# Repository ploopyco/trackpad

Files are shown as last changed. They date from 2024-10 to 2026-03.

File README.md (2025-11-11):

# The Ploopy Trackpad

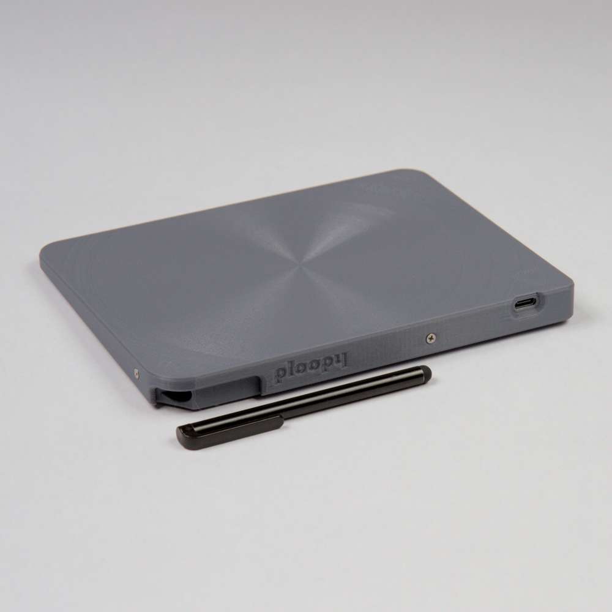
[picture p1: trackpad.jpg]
The Ploopy Trackpad


By some stroke of luck, you've made your way here. The Ploopy Trackpad. Your life will never be the same.

This repository contains all of the design and production files necessary to make a Ploopy Trackpad. We've also included some kick-ass documentation on how to get it made, assemble it, and program it [which you can find here](https://ploopyco.github.io/trackpad/).

What are you waiting for? Your new life awaits.

## QMK?!

Kits bought from the [Ploopy store](https://ploopy.co/product-category/trackpad/) come with QMK preloaded. [Check out the documentation](https://ploopyco.github.io/trackpad/) for instructions on how to load new firmware onto your device. (It's super easy!)

The firmware for the Trackpad hasn't been merged into QMK at the time of this commit, so for now, [firmware can be found here](https://github.com/ploopyco/qmk_firmware/tree/multitouch_experiment).

The firmware hex file that ships with all Trackpads is included in this repository as well, as `ploopyco_pavonis_default.uf2`.

A version of the firmware that is used for debugging and development is included here, as `ploopyco_pavonis_debug.uf2`. Don't use this firmware unless you need to use the [Maxtouch Debug App](https://ploopyco.github.io/trackpad/appendices/debugapp/).

## Under what license is this released?

As per QMK's licensing requirements, the firmware for the Ploopy Trackpad is released under GPLv3. Hardware design files, including electronics and mechanical files, are released under OHL CERN v2-S. Check the respective directories for full license text.

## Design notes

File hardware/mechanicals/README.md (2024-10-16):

## Only one file? Where are the parts?

The STEP/STL files contain all of the plastic parts in one file. Doing it this way preserves the assembly information, showing how the parts are supposed to fit together, as well as the expected clearances between parts. It also bundles all of the parts for a given revision together, so there's no accidental mixing of parts from different revisions.

## How do I print this?

You'll need to split the parts in the file up before you can print them. Most slicers can do this; if you have a compatible printer we recommend PrusaSlic3r, since that's the one we use in-house and have checked.

Note that submitting this file to some 3rd party print services will cause confusion, as they are expecting one body instead of many. To do this, you can use PrusaSlic3r to split the parts and then export each separately as an STL.

## How can I use the included .3mf file?

The .3mf file was generated using PrusaSlicer v2.5. The job was generated for Prusa i3 MK2S/MK3S/MK3S+ printers. It assumes the use of PLA that is printable at 200-230C. If you have that PrusaSlicer version, such a printer, and such filament, then you're in a lot of luck! We use a .3mf job that is very similar to this one to print these parts on our printing farm.

If you do not, then using the included .3mf file is likely going to cause you a lot of headaches. If this is the case, the included .3mf file should be considered **as a reference only**. If you use it at all, it is recommended that you look at it to see what kinds of print settings we use (gyroid infill, 0.3mm layer height, part orientation, etc.). However, you should use your own slicing software to generate the .gcode files for your printer.

## Why don't you include a .gcode file?

For your safety. Uploading a .gcode file onto a printer can be extremely hazardous if that .gcode file wasn't specifically generated for that printer. We don't want to come anywhere near that sort of scenario, so we are not going to upload a .gcode file.

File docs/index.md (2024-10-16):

# Home

So, you want to build a Ploopy Trackpad, eh? Or, maybe you want to replace some broken parts. Maybe you want to reprogram it. Or maybe you just want to know how it all works. No matter the motivation, this is the place to learn.

**Bought a kit and itching to get it built?** --> Get started by going to the [assembly instructions](assembly-instructions.md).

**Looking to purchase a kit with everything you need to build your own Ploopy Trackpad?** --> [Check out the Ploopy store](https://ploopy.co/product-category/trackpad).

**Building a Ploopy Trackpad from scratch?** --> Get started by going to [Appendix A: Printed circuit boards](appendices/pcbs.md).

---

*Copyright (C) 2024 Ploopy Corporation. Permission is granted to copy, distribute and/or modify this document under the terms of the GNU Free Documentation License, Version 1.3 or any later version published by the Free Software Foundation; with no Invariant Sections, no Front-Cover Texts, and no Back-Cover Texts. A copy of the license is included in the section entitled "GNU Free Documentation License".*

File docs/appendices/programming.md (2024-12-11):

# Appendix D: QMK Firmware Programming

## Working with QMK

Ploopy devices are fairly easy to program and reprogram, thanks to the excellent work by all of the developers and maintainers of the [QMK firmware suite](https://github.com/qmk/qmk_firmware).

## Pavonis? What's that?

`pavonis` is our internal codename for the Ploopy Trackpad. We don't always know what we're going to call the devices as we're designing them, so we assign codenames to them. This naming convention is also present in some public places, such as the QMK repository. If you see `pavonis` while you're working with QMK, just know that the Trackpad and `pavonis` are the same thing.

## Before you begin

If you have never used QMK before, go through [all of the steps in the QMK guide to set up your environment](https://docs.qmk.fm/#/newbs_getting_started).

QMK was built for keyboards, so you'll see lots of references to code that looks like the following:

`-kb <keyboard>`

Whenever you see that, use the following syntax:

`-kb ploopyco/pavonis`

and you'll be fine.

## Building the Ploopy device firmware

With your terminal window open and pointed at your QMK build environment, compile the firmware with the following command:

`qmk compile -kb ploopyco/pavonis -km default`

Alternatively, you can invoke the Makefile directly with the following:

`make ploopyco/pavonis:default`

For more details on building QMK firmware in general, see the [QMK firmware guide](https://docs.qmk.fm/#/newbs_building_firmware).

## Putting the Ploopy device into bootloader mode

Putting the Ploopy device into bootloader mode is very simple and straightforward.

1. Unplug the device from your computer.
2. Flip it over onto it's back. Unscrew the bootloader cap.
3. You should see two gold-covered holes exposed on the PCB once the cap is removed.
4. Get a paper clip (non-insulated, i.e. no plastic shit covering it) or a pair of tweezers, or some wire. Whatever you've got on hand that's metal.
5. Stick the paper clip or tweezers into the holes. You're trying to form an electrical connection between the two holes.
6. While you've got the two vias connected with your metal bridge, plug the Ploopy device into your computer.
7. The computer should recognise that a mass storage device was just plugged in. Once this is done, you should be able to drag and drop files onto the Ploopy device, as if the board was a USB drive. Feel free to remove the tweezers or paperclip at this point.

And that's it. While plugged in this way, the Ploopy device will accept new firmware.

If you want to upload a new firmware file (a ".uf2" file, like "ploopy_trackpad_v42069" or something), just drag it into the folder, and it'll automatically install on the Ploopy device and restart itself.

Whenever you want to put new firmware onto the Ploopy device, go through these steps again.

**TIP**: If your firmware is in some kind of strange state and uploading new firmware isn't fixing it, try uploading [a flash nuke](https://learn.adafruit.com/getting-started-with-raspberry-pi-pico-circuitpython/circuitpython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) to the Trackpad before flashing the new firmware. It wipes the memory of the Trackpad completely clean, which can help clear a few types of errors.

## And that's it!

Happy customizing!

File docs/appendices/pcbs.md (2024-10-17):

# Appendix A: Printed circuit boards

## Buying boards from us
Getting the Ploopy boards made can be complex, and expensive, especially if you only need one set. [That's why we sell kits with everything you need to build a Ploopy Trackpad](https://ploopy.co/product-category/trackpad/). Here's why that's great for you:

- You get a PCB with all components soldered
- The firmware is already programmed on the microcontroller, so you won't have to program it
- It'll cost a hell of a lot less than if you do a production run of PCBs just for yourself
- You won't have to order components and wait while they come in
- We guarantee that it works

Just something to consider. You're smart. You'll figure it out.

## Making your own boards

Want to make your own Ploopy Trackpad boards? Great! Less work for us. Seriously, though, only choose this option if you know what you're doing. You don't want to embarrass yourself, do you?

### Step 1: Order the PCBs from a PCB production company

Here are the most important configurations you'll need to communicate to the company:

- 6 layers
- FR-4, TG 150-160 (basically, whatever the cheapest option is)
- 1.6mm thickness
- 6/6mil track/spacing distance
- 0.3mm minimum hole size
- ENIG surface finish, but you can go with HASL if you don't care about lead poisoning
- 1oz copper thickness for both outer and inner layers
- Choose whatever colours you want for solder mask and silkscreen; we like white solder mask and black silkscreen

If something is missing from here, it's not really important.

At some point, you'll have to upload design files to the production company. Use the [electronics source files](https://github.com/ploopyco/trackpad/tree/master/hardware/electronics) to generate manufacturing files (you'll have to convert them from their native Altium format if you're using some other platform). That should contain everything you need to get the boards made. If the production company rejects this package, however, you'll need to address the issue yourself.

### Step 2: Order the electronics components

All of the components are described in the schematics of the PCBs. Ordering the components is left as an exercise for the reader.

A complete list of all of the components can be found in the electrical design files.

### Step 3: Get the necessary tools

- PCB
- All of the electronics components
- A hot air rework tool
- Solder paste
- A printout of the schematics

### Step 4: Solder the components to the boards

Once you've got the PCBs and all of the components, print out the schematics. Use the schematics to match the reference designators on the PCBs to the reference designators on the schematics, and then get to soldering.

If you've never soldered surface mount components before, or want a refresher on how to solder, we recommend [this video on using an iron to solder surface mount components](https://www.youtube.com/watch?v=3NN7UGWYmBY), and [this video on using a hot-air soldering station](https://www.youtube.com/watch?v=c_Qt5CtUlqY).

### Step 5: All done!

Congrats, you finished assembling the electronics! Pat yourself on the back.

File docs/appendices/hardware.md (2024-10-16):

# Appendix C: Hardware

# Buying hardware from us

Getting all of the hardware on your own can be tricky because the parts you select may not fit perfectly. [That's why we sell kits with everything you need to build a Ploopy Trackpad](https://ploopy.co/product-category/trackpad/). Here's why that's great for you:

- Everything is guaranteed to fit together perfectly
- Everything is guaranteed to work as intended
- You'll end up saving money - probably quite a bit of money - by not spending on extra parts

Your call. You'll sort it out.

# Getting your own hardware

This guide was a bit light on detail in the other sections, and that's because the hardware has to conform to many specifications. They'll all be listed here.

First, a complete list of all the hardware you'll need:

- 4x Small Screws
- 4x Friction Pads
- 1x Tape

We'll be going over all of them in detail. There will be mentions of *critical specifications*; if you're going to be sourcing your own parts, **you must get parts that conform to the critical specifications**. If you go off-menu, the parts will not fit the way that we intended when we designed the trackball. That might mean that your trackball **doesn't work**.

Let's get cracking.

## Small Screws

Here are the critical specifications:

- \#2
- 3/8" length

## Friction pads

Here are the critical specifications:

- Circular shape
- Up to 3/4" diameter
- Up to 1/8" thickness
- Non-slip

## Tape

We use **3M 467MP** adhesive transfer tape in dimensions of 6" x 4". If you do not use this specific tape, you may find that the tracking is extremely erratic, or may not function at all. If you decide to use other tapes, you will be responsible for retuning the Trackpad.

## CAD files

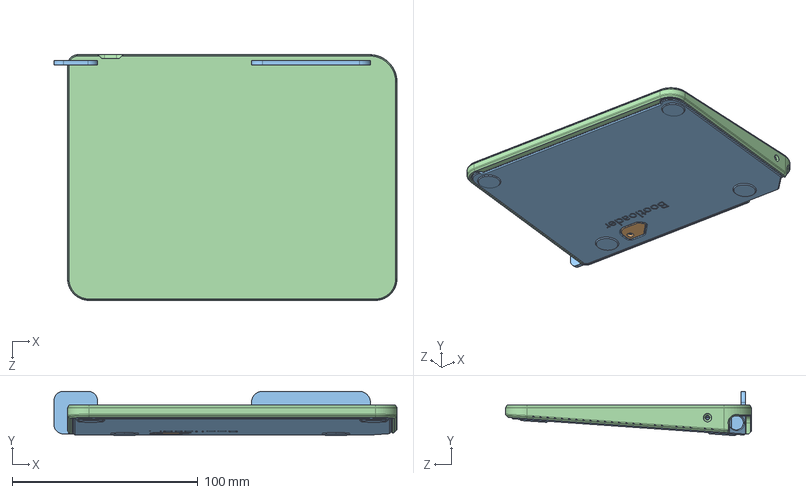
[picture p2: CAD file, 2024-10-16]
hardware/mechanicals/PloopyTrackpad-RevA.STEP
184.5 x 23.9 x 132.2 mm

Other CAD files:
hardware/mechanicals/PloopyTrackpad-RevA.3mf
hardware/mechanicals/PloopyTrackpad-RevA.STL

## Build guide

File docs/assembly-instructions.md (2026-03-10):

# Ploopy Kit Assembly Instructions

## BEFORE YOU DO ANYTHING, READ THIS FIRST.

**Do not flash new firmware until you've verified that the electronics are all working.**

That means, finish building the trackpad, plug it in, use the stock firmware for about five minutes. Verify that the cursor is moving, and all the buttons are working.

Once you've verified that it all works, you're good to go flashing new firmware.

## Main Instructions

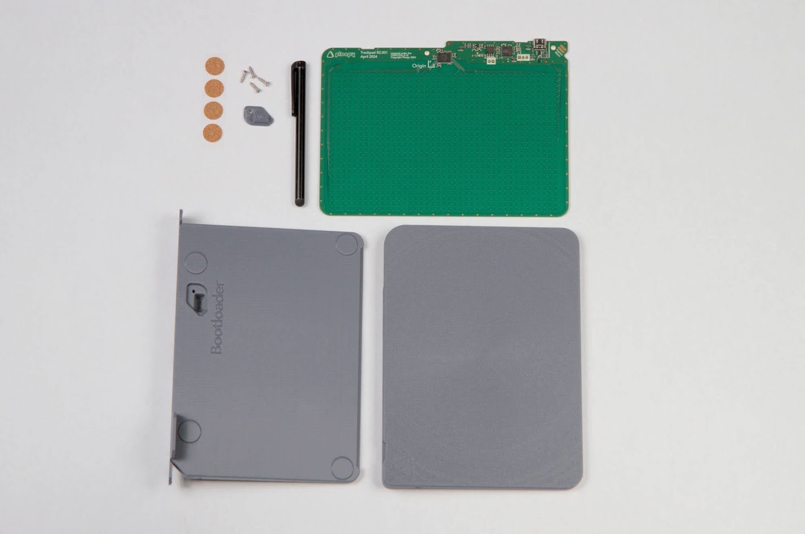
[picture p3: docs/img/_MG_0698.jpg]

In this section, you'll go over how to build a Trackpad from the official Ploopy Trackpad kit.

Here's how these instructions are structured*:

- 💡 Comments with a lightbulb are good information to know.
- ➡️ Comments with an arrow are commands. Execute them when you encounter them.
- ✅ Comments with a checkmark are verification steps. Check what they tell you to check, and if it's all good, move on.
- 📷 Comments with a camera are references to photos. Check the corresponding image for guidance.

Most steps have photos, so if you need some additional visual help, consult the images.

Note that some of these pictures were taken at different times, so they may show a bit of inconsistency in between steps.

*\* Thanks to [schneems](https://github.com/schneems) for his [great suggestions on how to write documentation](https://github.com/ploopyco/headphones/issues/37).*

### Step 1

- ➡️Get a #1 Phillips head screwdriver (or similar; you're looking for a small-ish screwdriver here).
- ➡️Get pair of pliers.
- 💡A pair of tweezers are optional, but they'll make future steps easier.

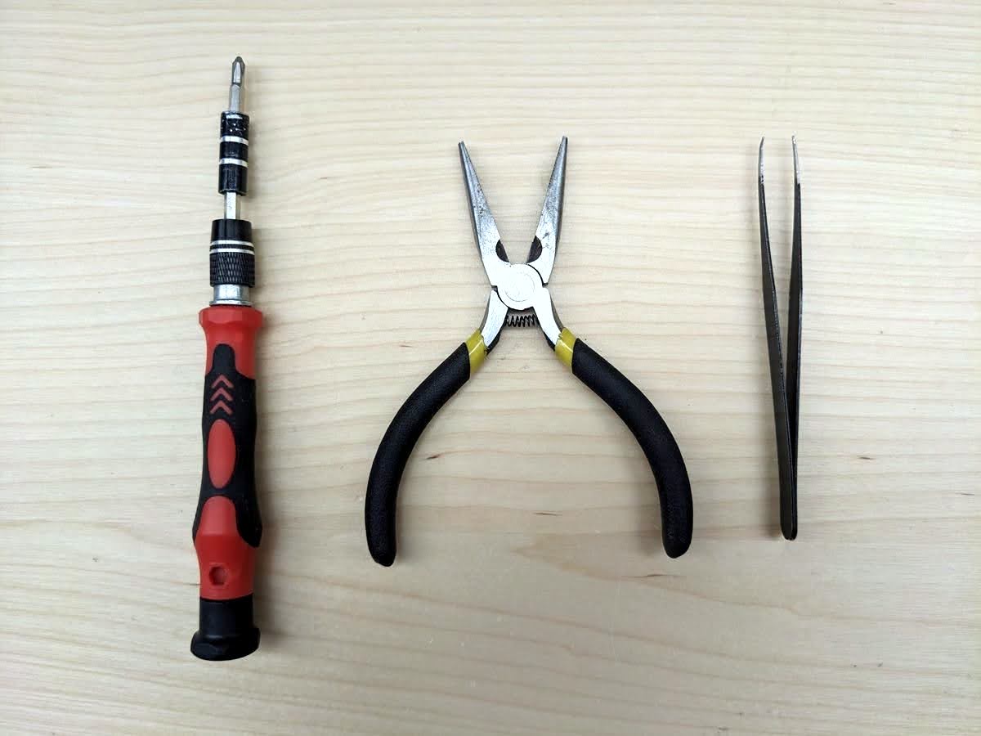
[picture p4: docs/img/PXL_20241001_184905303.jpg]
|  |
|:--:|
| *Figure 1: Necessary tools* |

### Step 2

- 💡 In the photo, a "tab" is being pulled by a pair of pliers.
- 💡 There may be up to two small tabs on the outside of the PCB.
- 💡 A pair of pliers will help to gently break the tabs off.
- ➡️ Break any leftover tabs off the PCB.

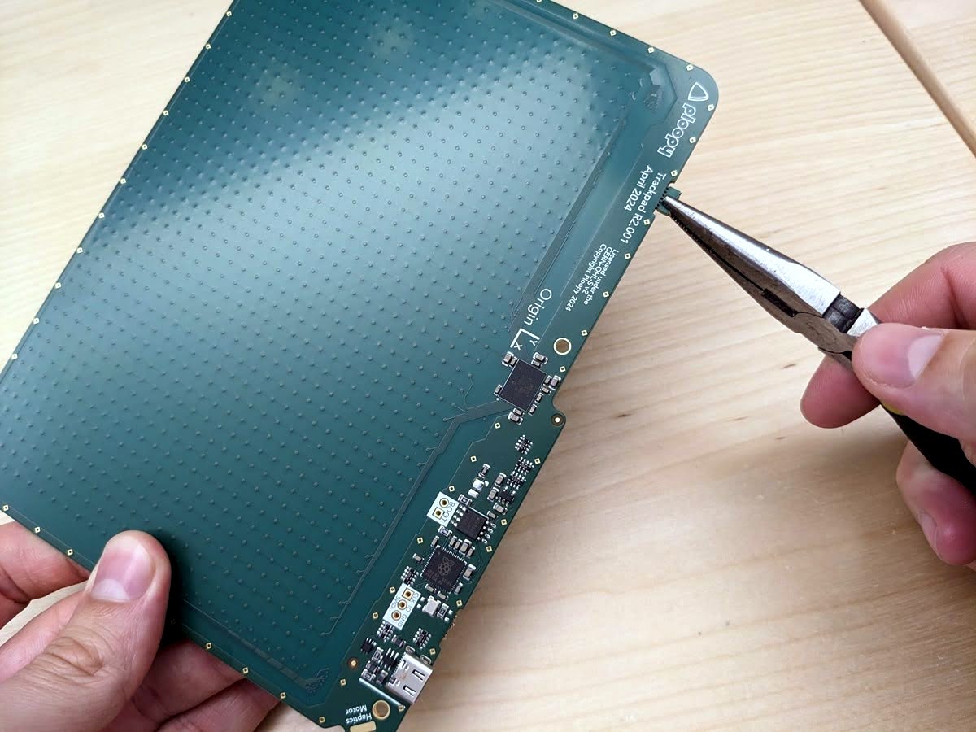
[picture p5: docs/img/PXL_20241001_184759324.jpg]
|  |
|:--:|
| *Figure 2: Breaking off tabs* |

### A Brief Note about Tape

- 💡 Trackpads shipped prior to March 2026 will have a large rectangle of 3M adhesive tape applied to the rear of the PCB. After March 2026, Trackpad PCBs will not have this layer of tape, as it was deemed unnecessary.
- 💡 If your Trackpad has tape on it, you do not have to peel the protective layer of tape off, and you do not have to stick the PCB to the plastic. Proceed through these instructions and ignore the tape.

### Step 3

- ➡️ Get the PCB and Front. 📷 *See Figure 3.1.*
- ➡️ Place the PCB into the Front. 📷 *See Figure 3.2.*
- ✅ Check that the USB port lines up with the hole in the Front, and that the PCB is sitting flat against the Front. 📷 *See Figure 3.3.*

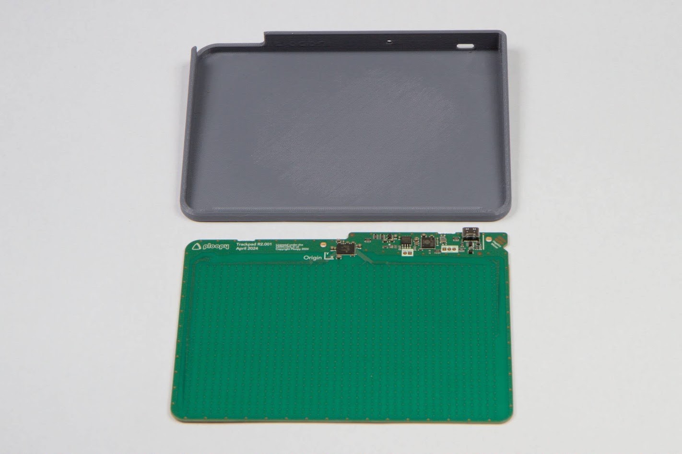
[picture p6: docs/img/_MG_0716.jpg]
|  |
|:--:|
| *Figure 3.1: PCB and Front* |

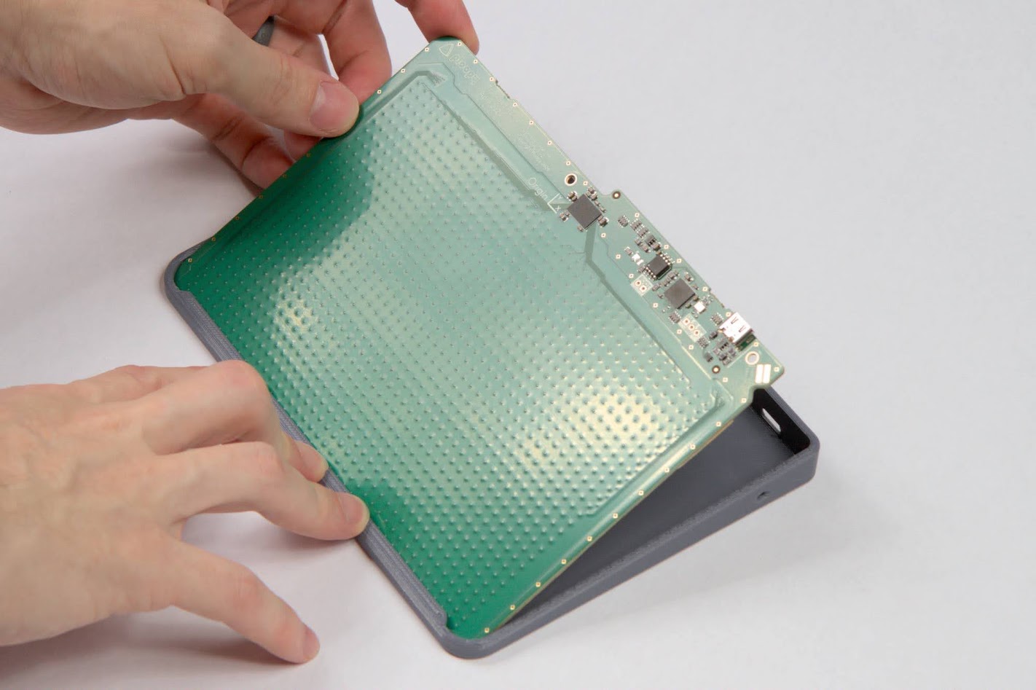
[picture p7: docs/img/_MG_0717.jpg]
|  |
|:--:|
| *Figure 3.2: PCB being placed into Front* |

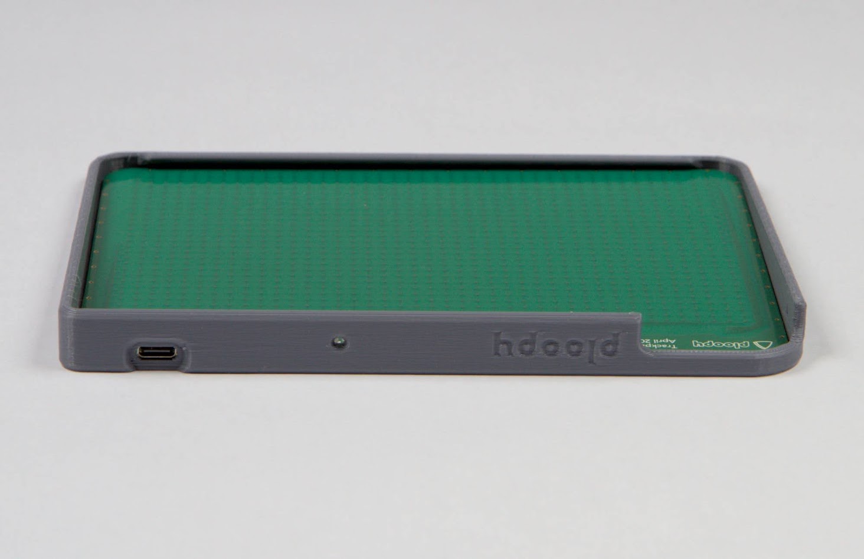
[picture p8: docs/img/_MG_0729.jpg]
|  |
|:--:|
| *Figure 3.3: PCB placed correctly, with PCB sitting flat and USB port lined up with hole* |

### Step 4

- ➡️ Get the Back. 📷 *See Figure 4.1.*
- 💡 Note the lip on the bottom of the Front.
- 💡 It might require a bit of force to press the Back into the assembly.
- ➡️ Place the Back into the assembly. 📷 *See Figure 4.2 and Figure 4.3.*

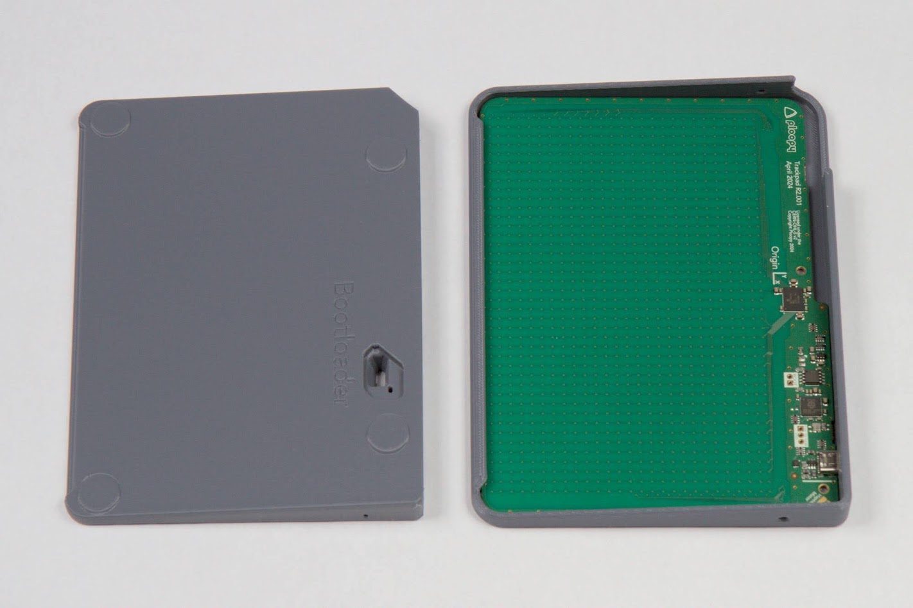
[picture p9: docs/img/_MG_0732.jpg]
|  |
|:--:|
| *Figure 4.1: Back and assembly* |

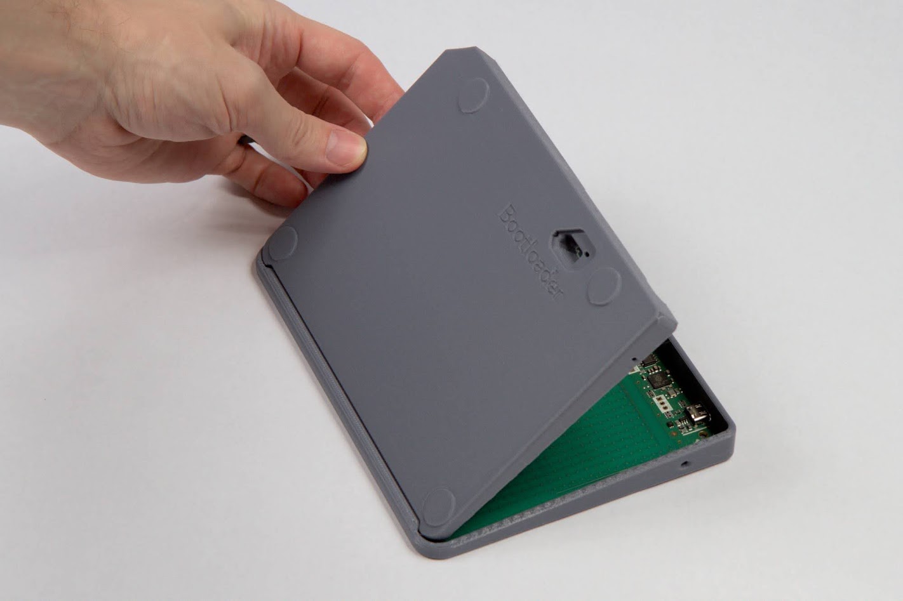
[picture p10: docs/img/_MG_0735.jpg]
|  |
|:--:|
| *Figure 4.2: Back being placed into assembly* |

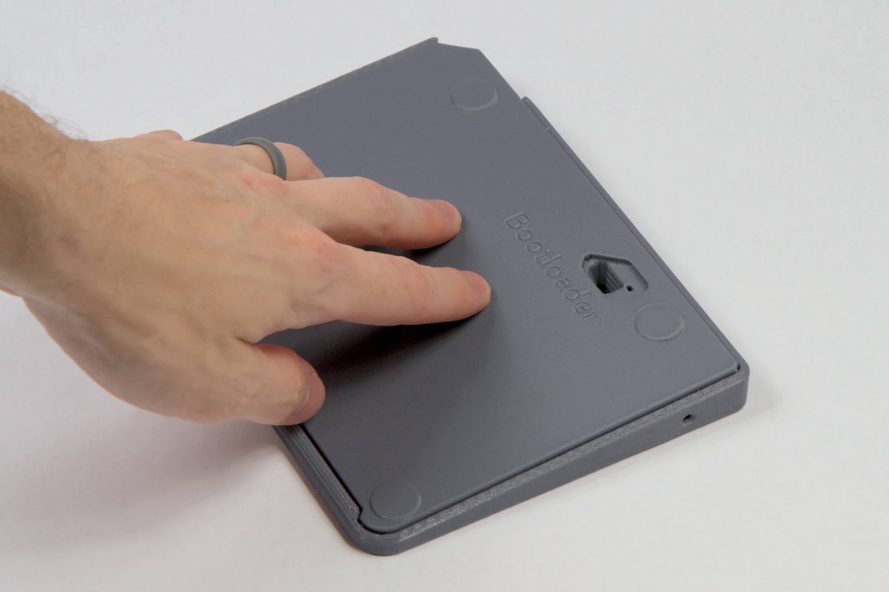
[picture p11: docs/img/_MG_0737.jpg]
|  |
|:--:|
| *Figure 4.3: Back being gently pushed into assembly* |

### Step 5

- ➡️ Get three screws.
- ➡️ Insert the three screws into the three holes in the Front. 📷 *See Figure 5.1, Figure 5.2 and Figure 5.3.*

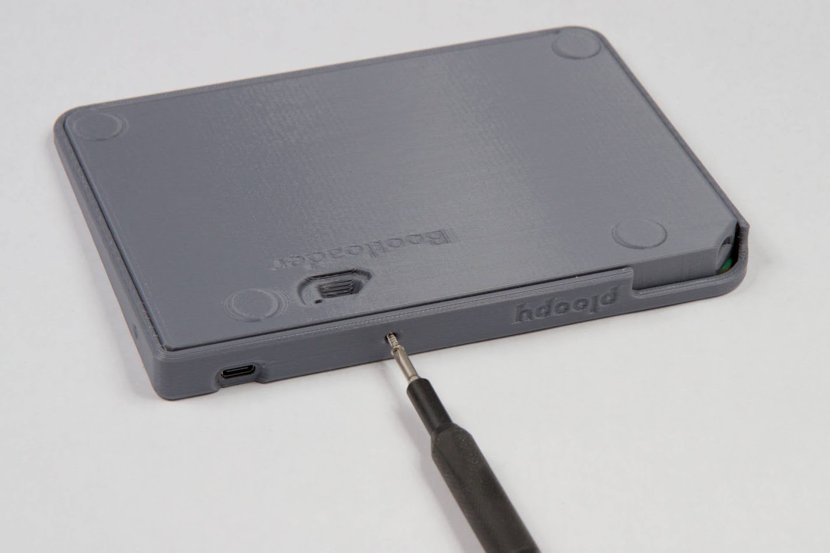
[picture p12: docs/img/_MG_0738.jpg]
|  |
|:--:|
| *Figure 5.1: Top screw being driven* |

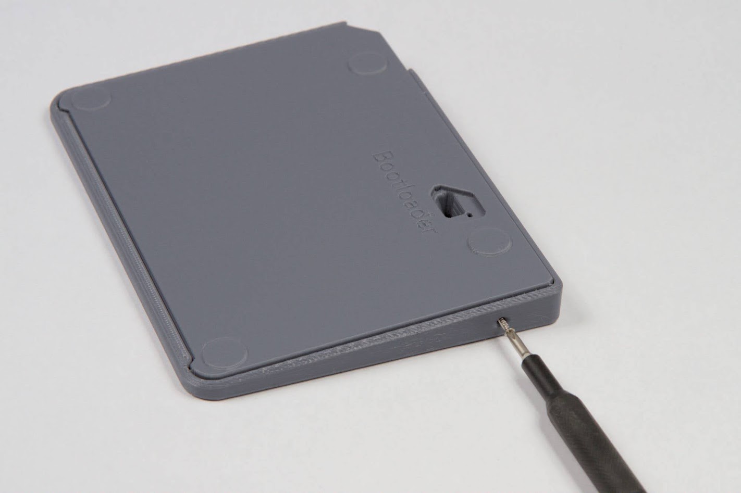
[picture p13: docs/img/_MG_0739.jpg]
|  |
|:--:|
| *Figure 5.2: Left screw being driven* |

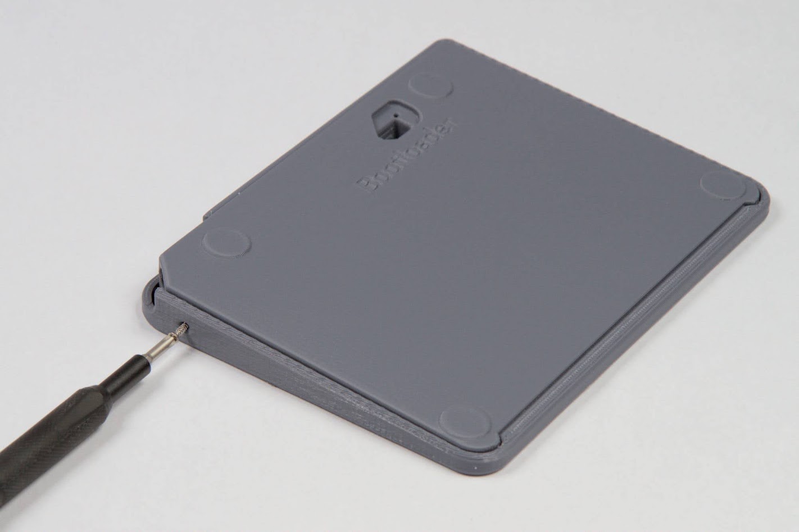
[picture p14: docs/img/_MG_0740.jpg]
|  |
|:--:|
| *Figure 5.3: Right screw being driven* |

### Step 6

- ➡️ Get the Bootloader Cap and a screw.
- ➡️ Place the Bootloader Cap into the Back.
- ➡️ Screw the Bootloader Cap into the Back.

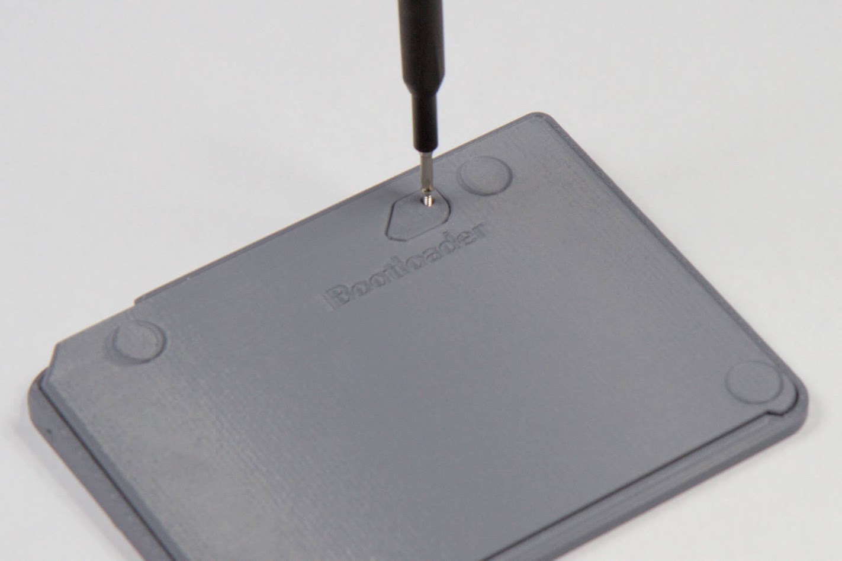
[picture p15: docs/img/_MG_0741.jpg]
|  |
|:--:|
| *Figure 6: Bootloader cap being screwed down* |

### Step 7

- ➡️ Get the friction pads.
- ➡️ Peel and stick the friction pads onto the Back.

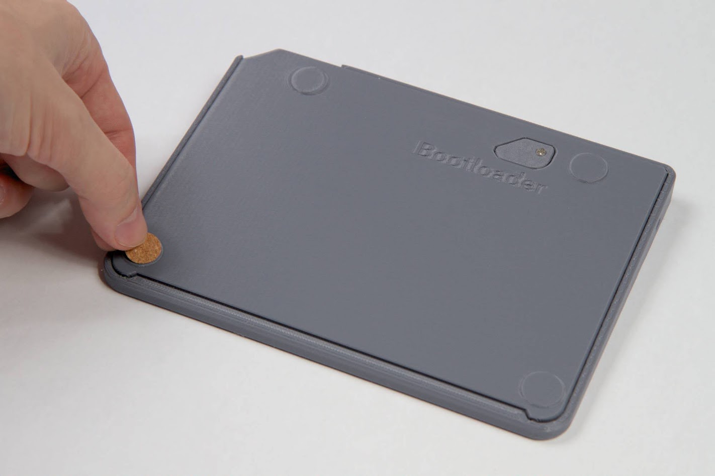
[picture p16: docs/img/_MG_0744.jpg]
|  |
|:--:|
| *Figure 7.1: Friction pad being stuck* |

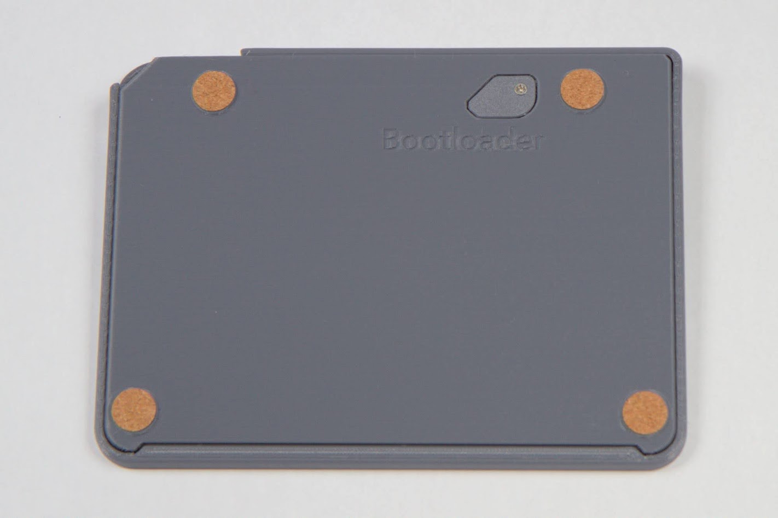
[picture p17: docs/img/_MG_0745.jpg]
|  |
|:--:|
| *Figure 7.2: Friction pads completed* |

### Step 8

- ➡️ Get the Stylus.
- ➡️ Insert the Stylus into the Back.

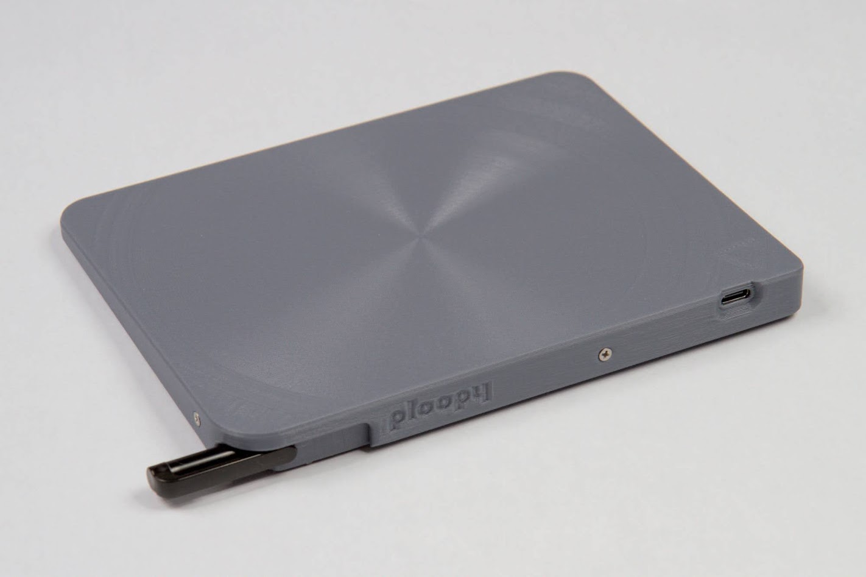
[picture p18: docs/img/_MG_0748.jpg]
|  |
|:--:|
| *Figure 8: Stylus being inserted into back* |

### Step 9

- ➡️ Plug the Trackpad into your computer.
- ✅ Check that moving your finger along the surface of the Trackpad moves the cursor.

### Step 10

- 💡 Congrats, you finished building the Ploopy Trackpad!
- 💡 It's done! Love it, use it, but don't you dare abuse it!

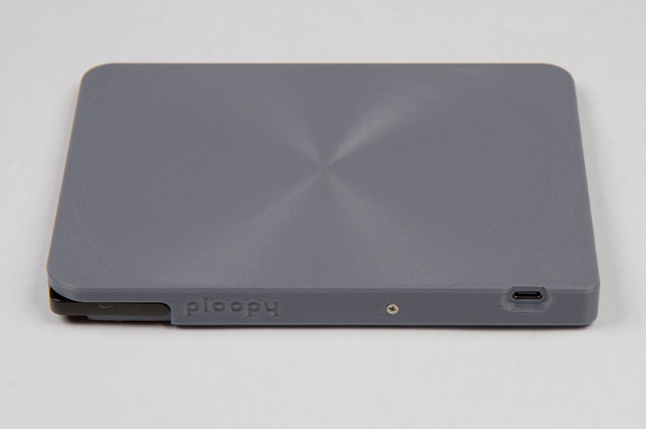
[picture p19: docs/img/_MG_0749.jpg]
|  |
|:--:|
| *Figure 10: You're done!* |

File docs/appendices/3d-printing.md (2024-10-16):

# Appendix B: 3D printed parts

# Buying 3D-printed parts from us
Not everyone has access to a 3D-printer. [That's why we sell kits with everything you need to build a Ploopy Trackpad](https://ploopy.co/product-category/trackpad/). Here's why that's great for you:

- You get all of the 3D-printed parts, guaranteed free of manufacturing defects
- You won't waste time spending hours tweaking settings
- We guarantee it will fit together *perfectly*

Consider it. You're a smartie. You'll get there.

# Printing your own parts

So, you have a printer and want to print your own parts? Great! We don't have specific instructions, since every printer setup is different. All of the STLs are available, and if you need to make tweaks, you can alter the design files.

Here are the settings we use when we print parts. **Note that these settings have only been tested on the Prusa i3 MK2.5S and MK3S.** If you have another printer, you may need to tweak these settings.

- PLA. The geometry of many of the parts is quite complex; trying to use other materials may not result in success.
- 0.30mm layer height. You can go finer than this if you want, but we haven't tested that. Going coarser is not going to work; first, it's going to feel rough on your hand, and second, it won't accurately capture the necessary detail.
- No support material is required anywhere. However, your printer must have the capability of bridging distances of up to 40mm.
- Orient the pieces so that flat sides are on the build plate.
- We like gyroid for infill pattern, but anything is probably good. Cubic, rectilinear, whatever.
- We use 0.4mm nozzles. We haven't tested other nozzle sizes.

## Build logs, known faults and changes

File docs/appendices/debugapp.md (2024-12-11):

# Appendix E: The Maxtouch Debug App

## The Microchip ATMXT1066TD

Trackpad tracking is quite a tricky thing to do. In the Ploopy Trackpad, the chip that we use to perform the tracking calculations is the **Microchip ATMXT1066TD** (which we'll call the **MXT1066** for the rest of this document).

The MXT1066 is a highly-advanced chip with many, many, *maaany* features. It has so many features that it's hard to keep track of them all.

To alter them quickly and see the effects that the alterations have, [George Norton's Maxtouch Debug utility](https://github.com/george-norton/maxtouch-debug/) is extremely useful. It looks something like this:

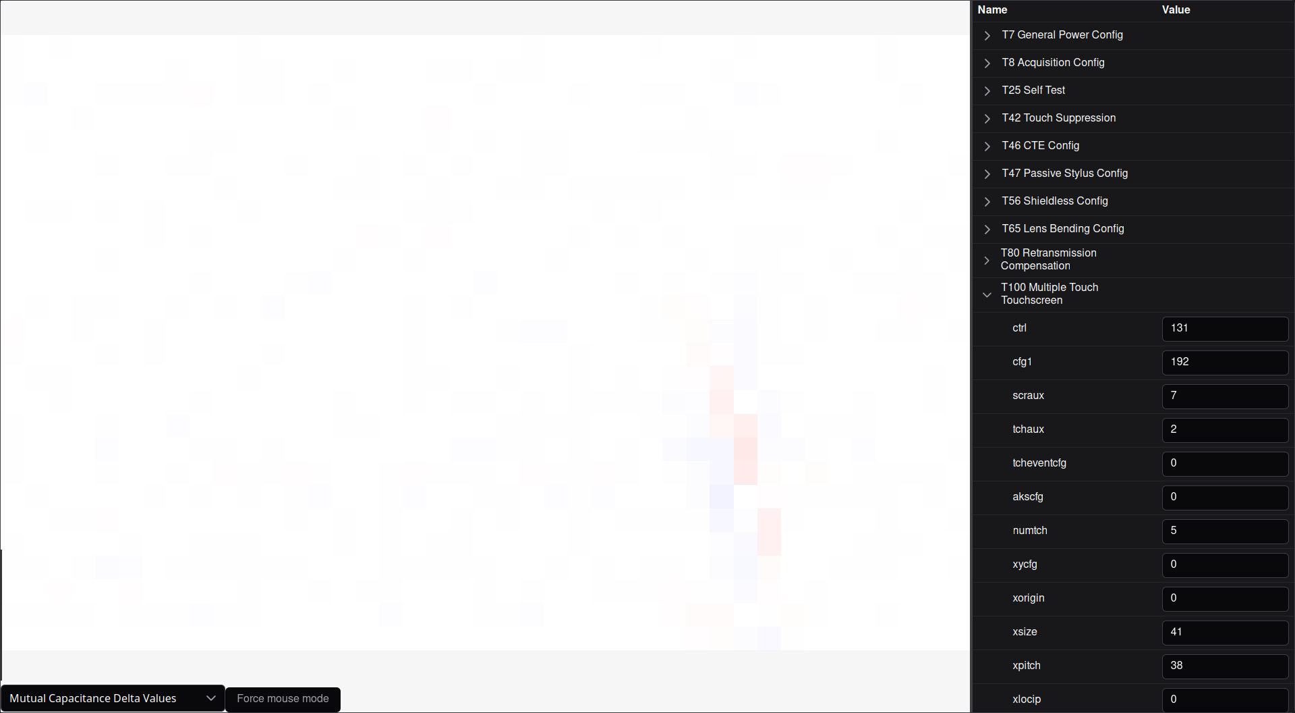
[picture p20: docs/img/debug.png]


## Debug firmware

In order to use the debug app, you'll need to flash the `debug` firmware onto the Trackpad, available [here](https://github.com/ploopyco/trackpad/blob/main/ploopyco_pavonis_debug.uf2).

If necessary, follow the guide in [Appendix D](programming.md) to put new firmware onto the Trackpad.

## Putting the Ploopy Trackpad into bootloader mode while using the `debug` keymap firmware

Putting the Ploopy Trackpad into bootloader mode while using the `debug` firmware is very easy. Just put all five fingers down on the trackpad surface at once! The computer should state that your Trackpad was disconnected, and that a mass storage device was just plugged in. Once this is done, you should be able to drag and drop files onto the Ploopy device, as if the board was a USB drive.

## How to use it, though?

This, unfortunately, is the tricky part. Microchip places the documentation for the MXT1066 under NDA, which means that we are unable to share our copy with you. However, if you have a Microchip account, you can download the documentation for yourself quickly and easily.

The MXT1066 documentation has a full explanation of all of the features that are broken out in the debug utility.

Alternatively, you could just try changing things and see what happens...!

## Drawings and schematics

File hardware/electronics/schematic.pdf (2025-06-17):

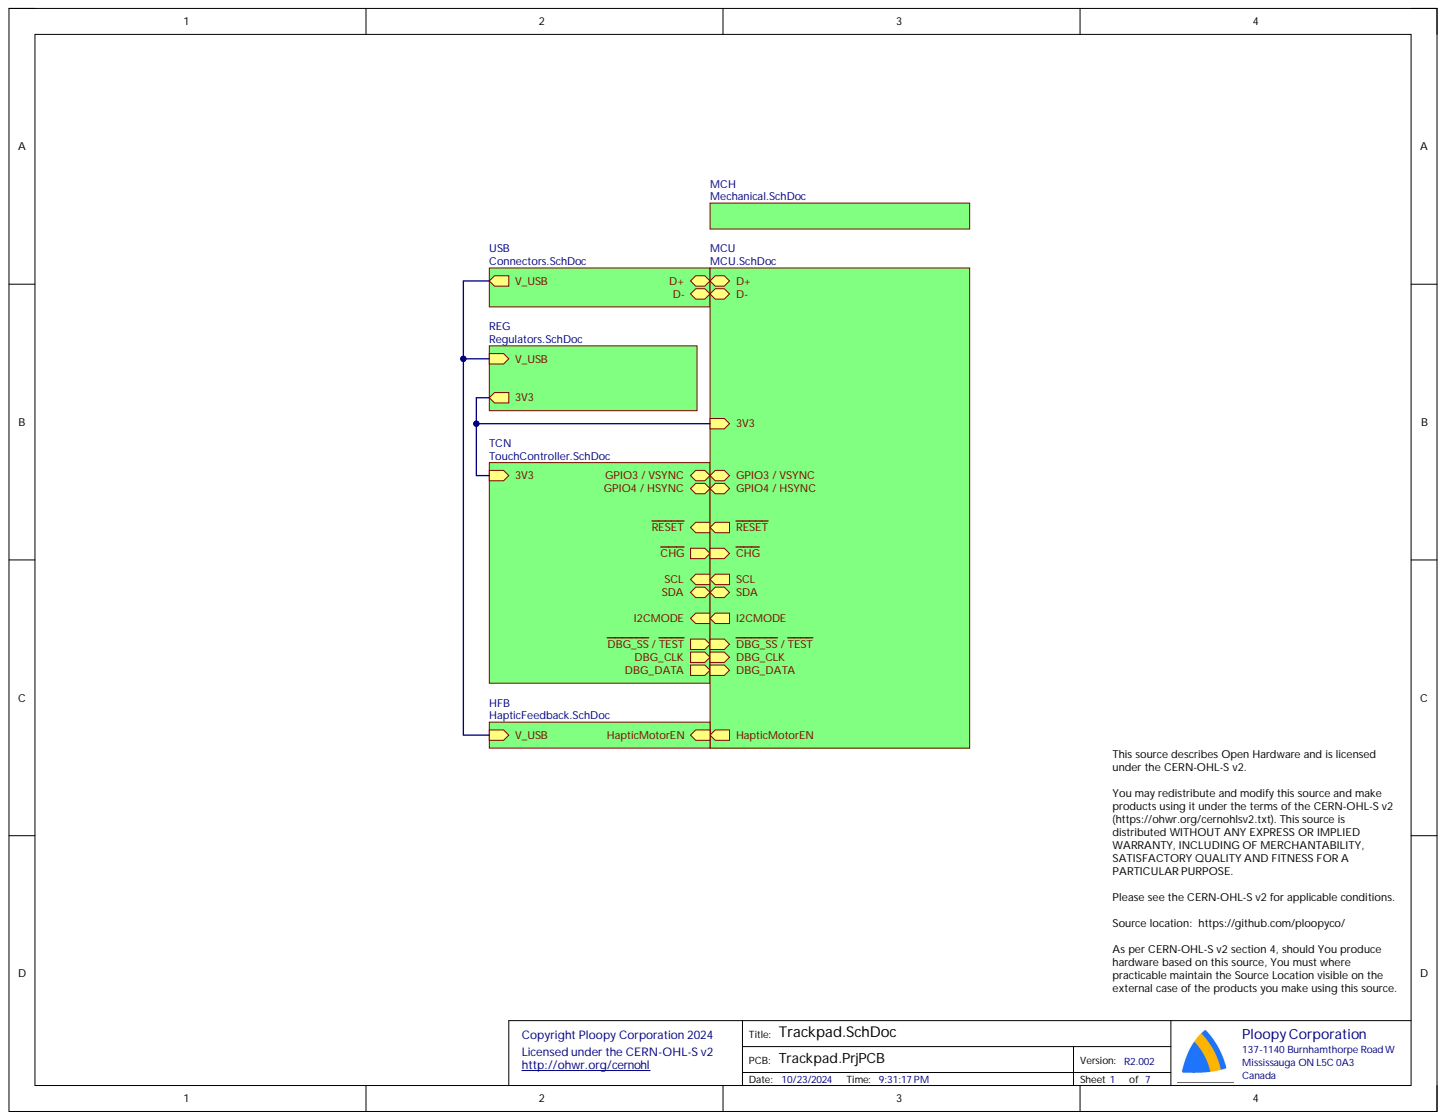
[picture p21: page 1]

This source describes Open Hardware and is licensed
under the CERN-OHL-S v2.

You may redistribute and modify this source and make
products using it under the terms of the CERN-OHL-S v2
(https://ohwr.org/cernohlsv2.txt). This source is
distributed WITHOUT ANY EXPRESS OR IMPLIED
WARRANTY, INCLUDING OF MERCHANTABILITY,
SATISFACTORY QUALITY AND FITNESS FOR A
PARTICULAR PURPOSE.

Please see the CERN-OHL-S v2 for applicable conditions.

Source location: https://github.com/ploopyco/

As per CERN-OHL-S v2 section 4, should You produce
hardware based on this source, You must where
practicable maintain the Source Location visible on the
external case of the products you make using this source.

Copyright Ploopy Corporation 2024
Licensed under the CERN-OHL-S v2
http://ohwr.org/cernohl

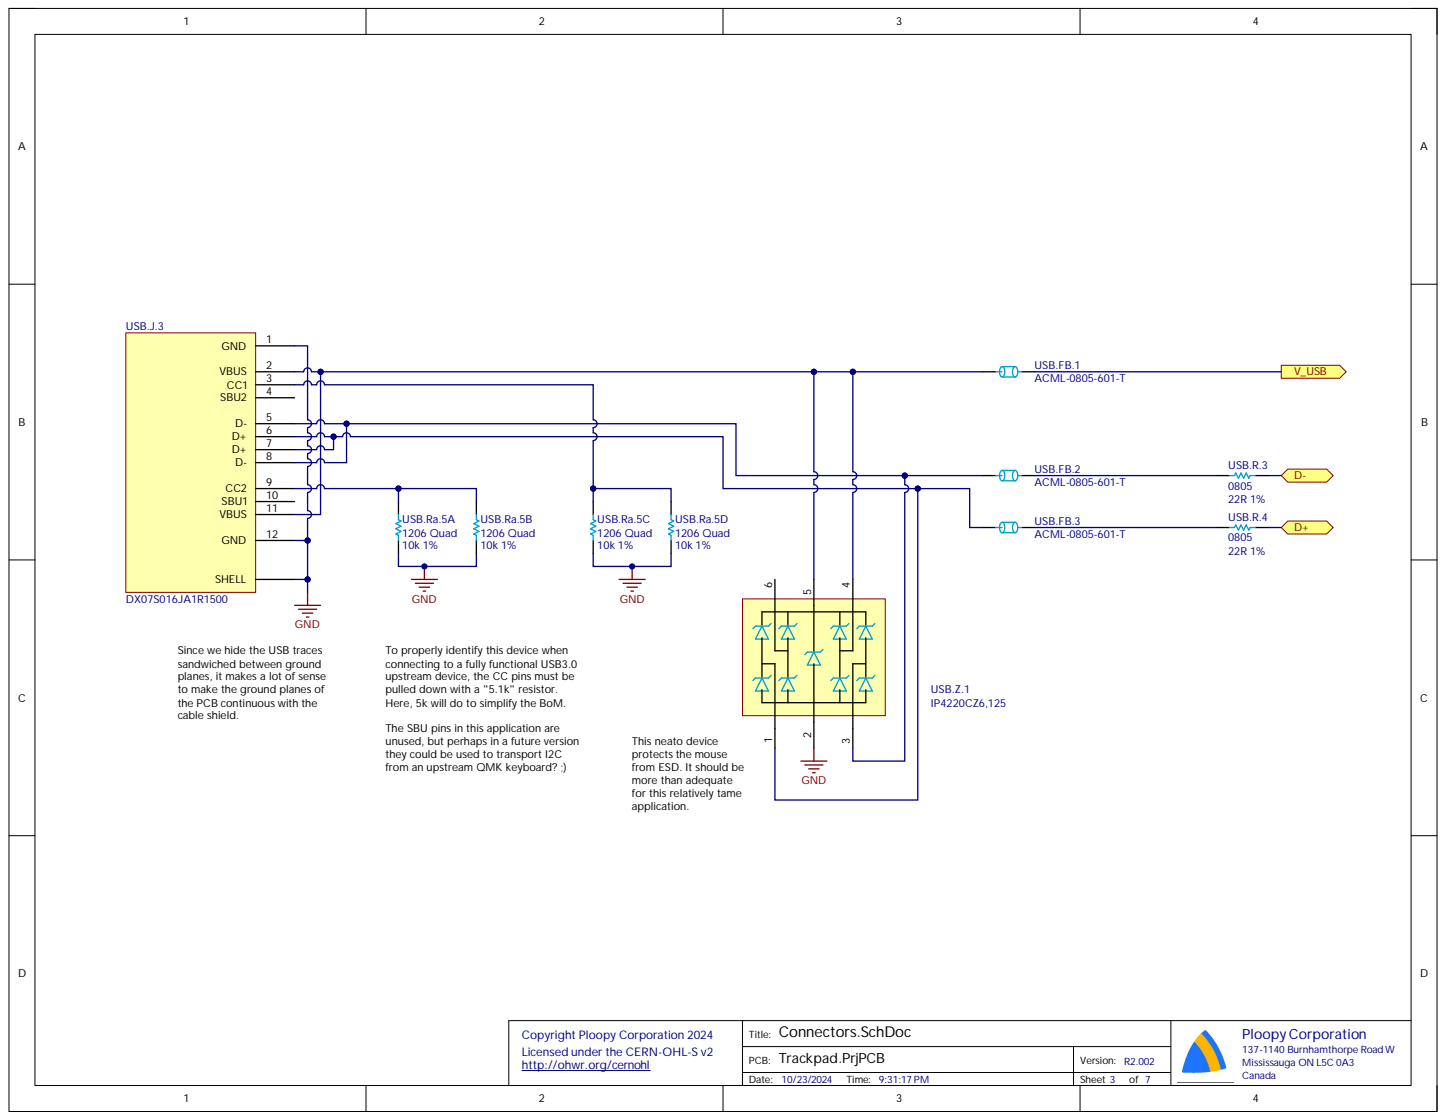
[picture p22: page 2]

Since we hide the USB traces sandwiched between ground planes, it makes a lot of sense

To properly identify this device when
connecting to a fully functional USB3.0
pulled down with a "5.1k" resistor.
Here, 5k will do to sim

to make the ground planes of
the PC
cable shield

The SB
unused, but perhap
they could be used to trans
from an up

U pins in this ap

This neato device protects the mouse

from ESD. It should be more than adequate

for this relatively tame

Cop
Licensed under the CE
http

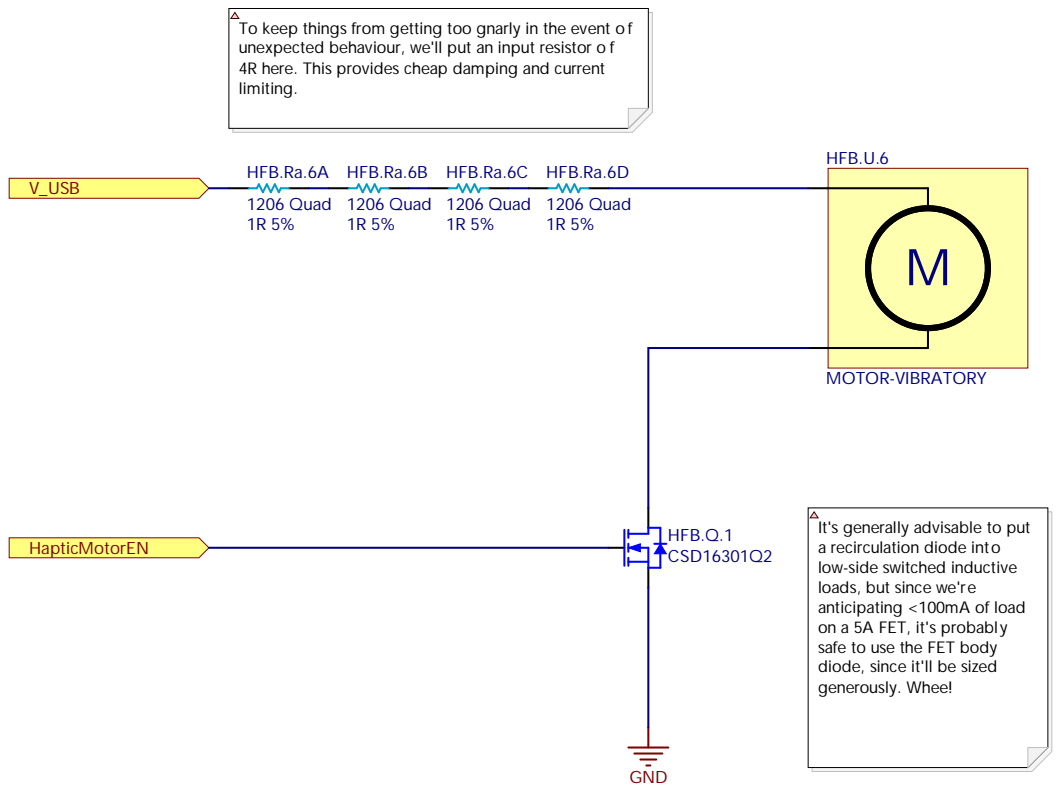
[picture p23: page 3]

To keep things from getting too gnarly in the event of
unexpected behaviour, we'll put an input resistor of
4R here. This provides cheap damping and current
limiting.

It's generally advisable to put
a recirculation diode into
low-side switched inductive
loads, but since we're
anticipating <100mA of load
on a 5A FET, it's probably
safe to use the FET body
diode, since it'll be sized
generously. Whee!

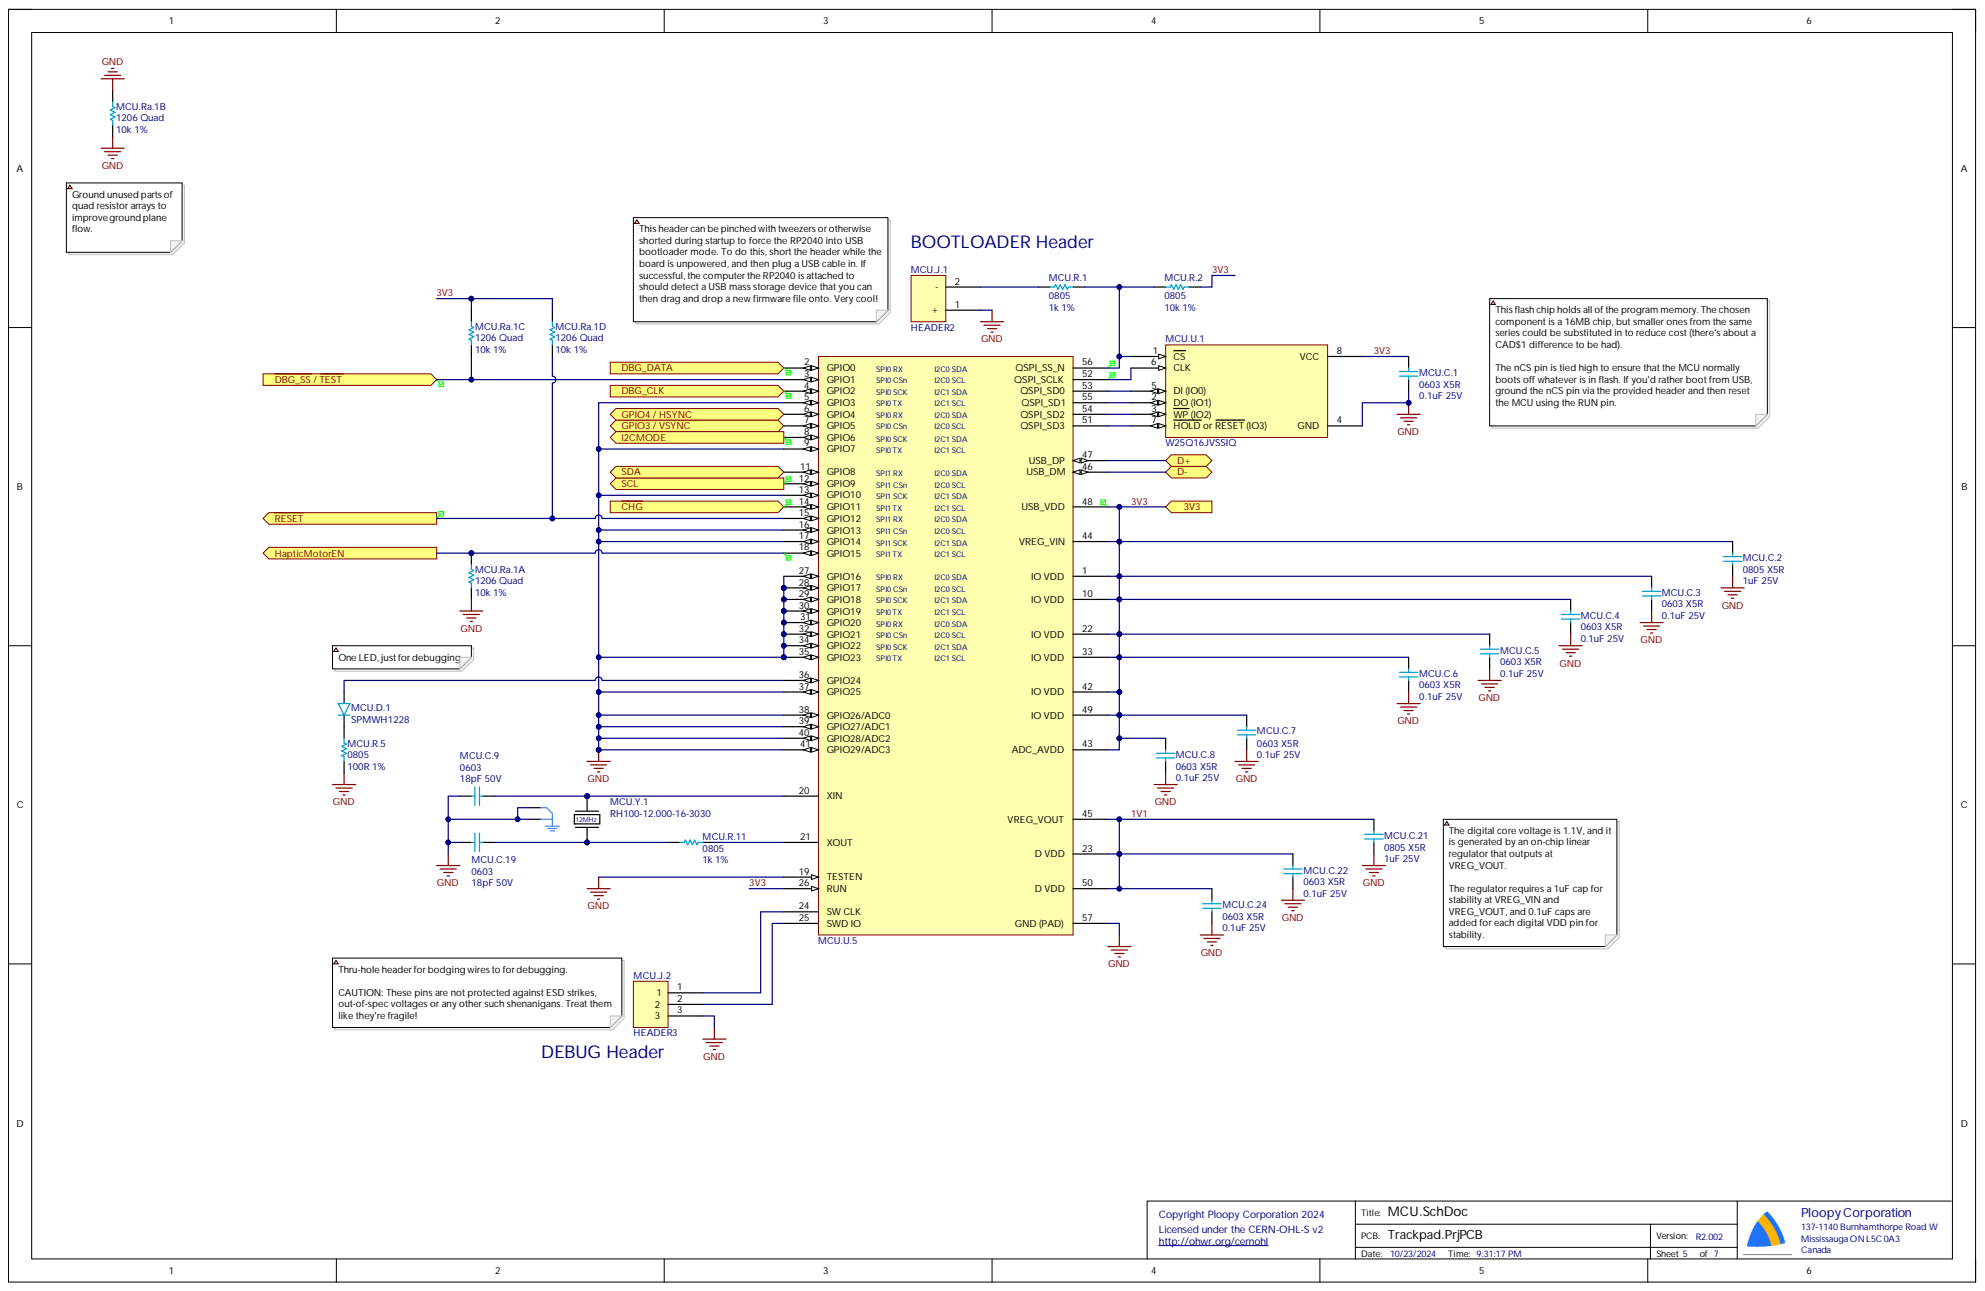
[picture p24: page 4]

N C G P I O3 / VSY N C I2C M ODE | 6 | 3

9 | W25Q16J VSSI Q D-

SDA SC L

Cop y rig h t Ploop y Cor pora tion 2 02 4 Lice n s e d u n d e r t h e CE R N -OH L -S v 2 h t t p : //ohwr .org /ce r noh l | T i t l e : MC U.S c h Doc | Plo opy C o rpo ra t i o n 1 3 7-1 1 40 B u r n h a m t hor p e Roa d W M i ssi ssa u g a O N L 5C 0A 3 C a n a d a

PC B : Trackpad.P rj PC B | V e rsion : R 2 . 002

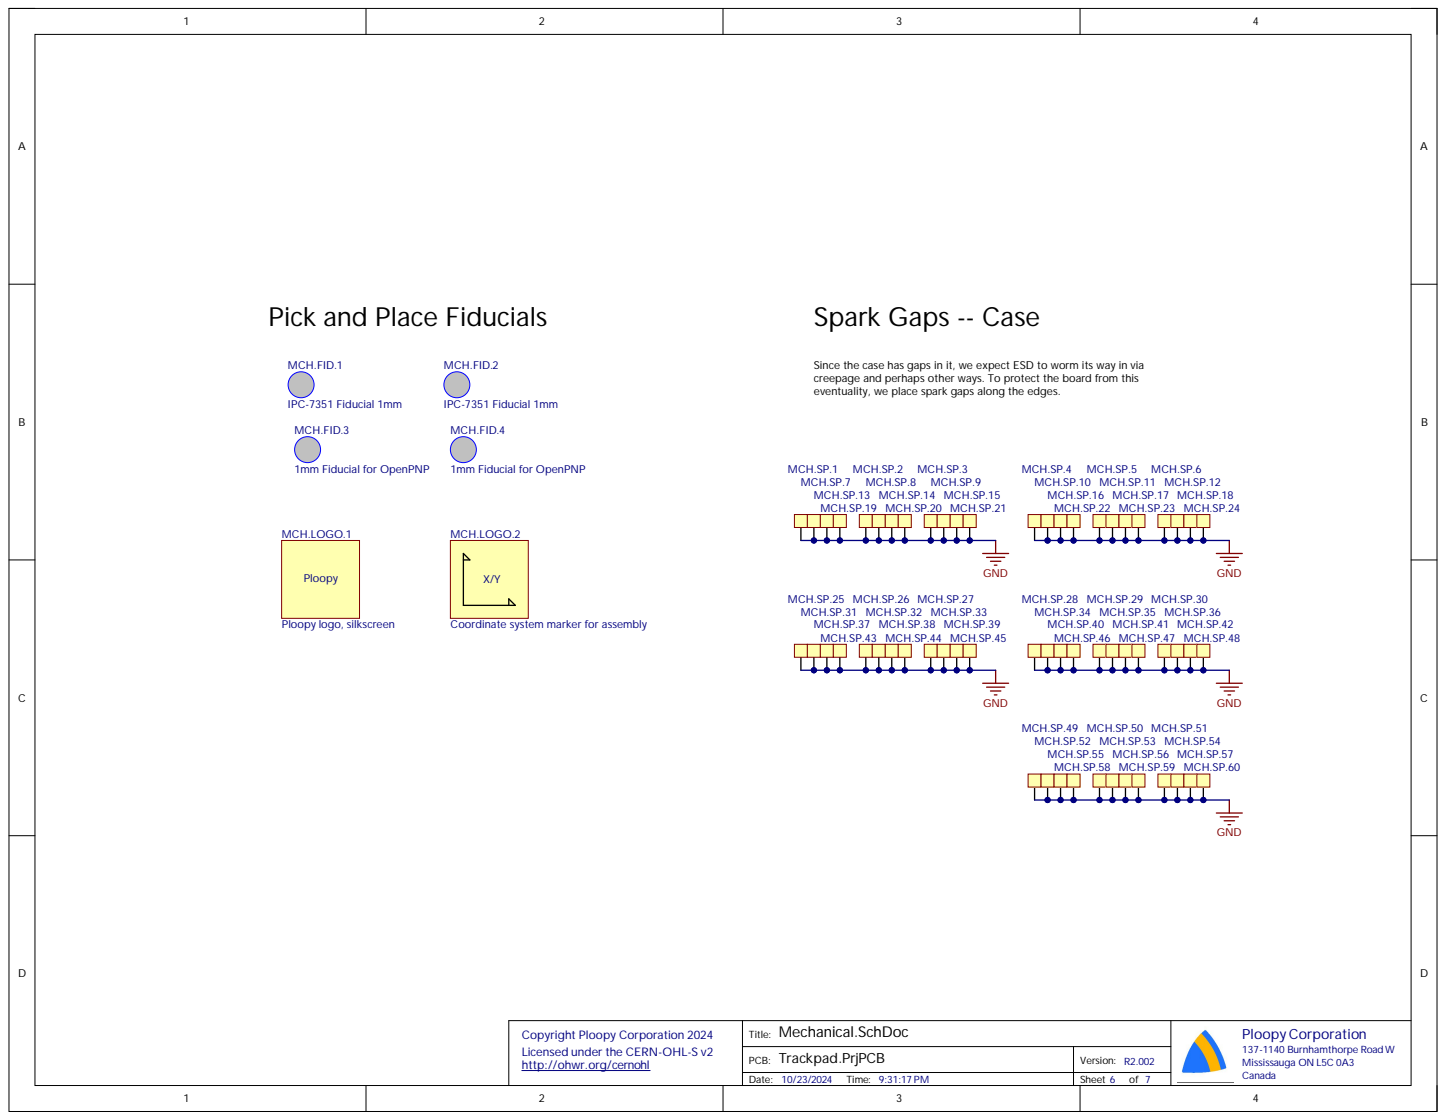
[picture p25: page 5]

Pick and Place Fiducials

Since the case has gaps in it, we expect ESD to worm its way in via
creepage and perhaps other ways. To protect the board from this
eventuality, we place spark gaps along the edges.

Coordinate system marker for assembly

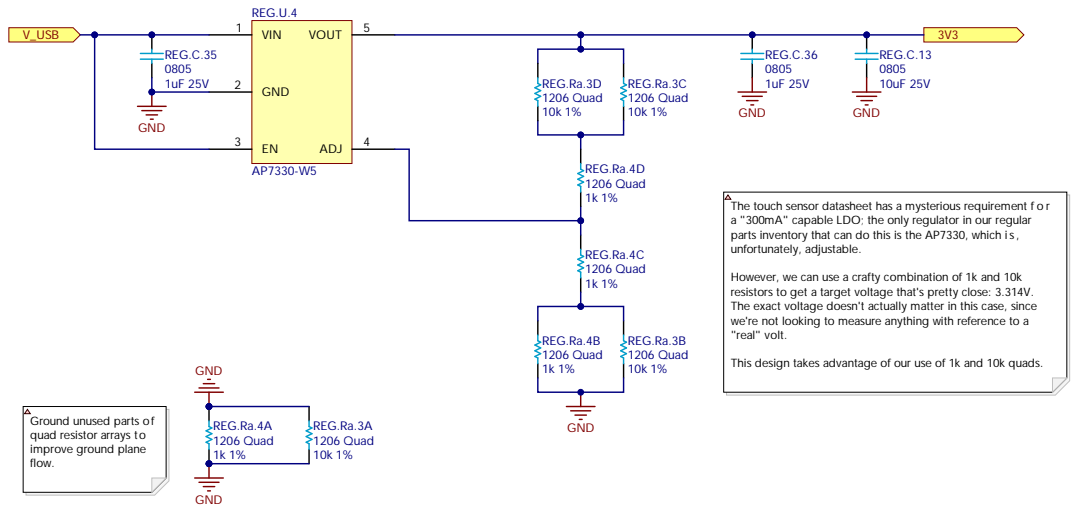
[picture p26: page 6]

do this is th

Cop
Licensed under the CE
http

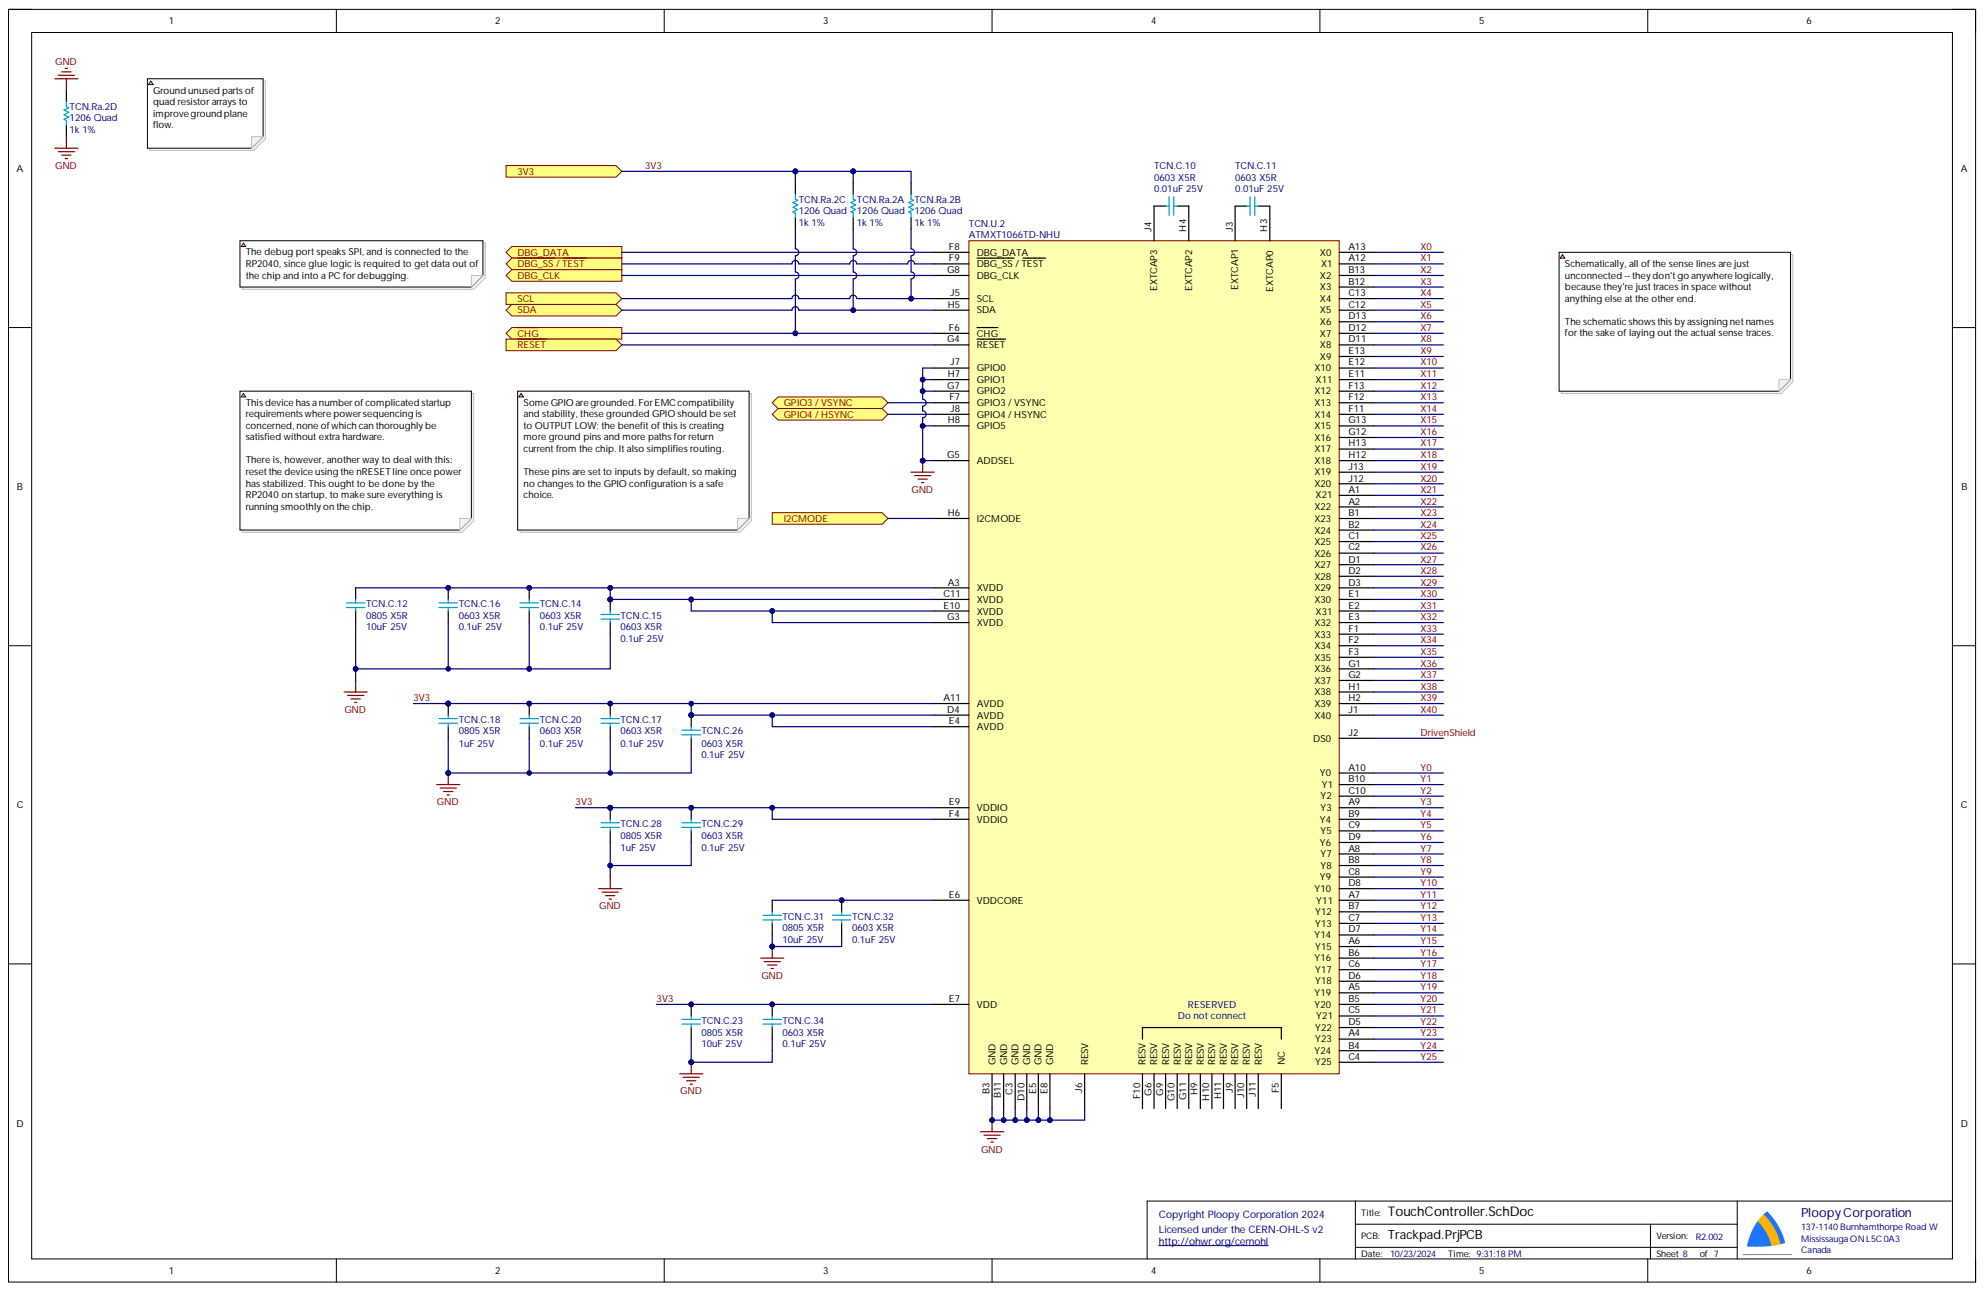
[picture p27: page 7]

C11
E10
G 3

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

PC B : Trackpad.P rj PC B | V e rsion : R 2 . 002
